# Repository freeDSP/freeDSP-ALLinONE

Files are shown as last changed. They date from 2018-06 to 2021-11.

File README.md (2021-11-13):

# freeDSP ALLinONE
BOARD STATUS: READY TO BE BUILT

Upgrade of the [freeDSP Classic SMD-B](https://github.com/freeDSP/freeDSP-CLASSIC-SMD-B/blob/master/README.md)

LICENCE: Creative Commons Attribution Share-Alike 4.0 license

http://freedsp.cc

## About

The freeDSP is an open-source digital signal processor family for the do-it-yourself community. The applications range from active loudspeaker concepts (digital crossovers, bass enhancement, ...) and room equalization over advanced musical effect processors to car audio signal processing. 

The _freeDSP ALLinONE_ is an all-in-one version of the original _freeDSP Classic SMD-B_ with a few improvements, upgrades and changes.
It features four amplified analog outputs as well as S/PDIF in- and output (optical and RCA).
This board has been designed using the Cross-Platform Open Source Tool [KiCad](http://kicad.org/).

More informations kann be found on the [freeDSP website](http://freedsp.cc)

You can find a PDF version of the schematic in the SOURCES folder (LINK)

## Links

[freeDSP Website](http://freedsp.cc)

[Documentation in Google Doc](https://docs.google.com/document/d/1258PKKEvrk1GpFIaAHhm8G6f0HHNBfSL8KVq2VGgUKc/edit?usp=sharing)

[freeDSP Guidelines](https://github.com/freeDSP/WIKI-AND-GENERAL-TOPICS/wiki/freeDSP-Guidelines)

## Git usage

#### How to setup local repository
- Change to your FreeDSP directory
- Clone the repository (including submodule)  
 `git clone --recursive https://github.com/freeDSP/freeDSP-ALLinONE.git` 
- Change to the newly created ALLinONE directory
- Checkout a branch for the library submodule, if you want to modify it as well
  `git submodule foreach 'git checkout 'master''`
- Open the project file in KiCad

#### How to update the local copy
- To update the project  
  `git pull`
- To update the library  
  `git submodule update --remote --merge`

#### To commit and push local changes
- If you modified something in the LIBRARY folder, change to the LIBRARY folder and run  
  `git add .` (Only required if files were added)  
  `git commit -am "Message"`  (Describe what you changed)  
- Change to the project root directory and run
  `git add .` (Only required if files were added)  
  `git commit -am "Message"`  (Describe what you changed)    
- In the project directory run  
  `git push --recurse-submodule=on-demand`  

#### Define alias to make things shorter
- In the project directory run
  `git config alias.supdate 'submodule update --remote --merge'`  
  `git config alias.spush 'push --recurse-submodules=on-demand'`  
- Afterwards you can use `git supdate` to update the submodule and `git spush` to push any commited changes  

#### Other useful commands
- `git status`  
  Shows general information about the current branch, uncommited changes, not yet added new files and more
- `git diff`  
  Shows uncommited changes
- `git reset --hard origin/master`
  Reset all files to the current status of the dev-hs-01 branch on the Github repository  
  **Careful** This deletes all local changes, so make sure all changes you made and you do not want to delete are pushed to the remote repository

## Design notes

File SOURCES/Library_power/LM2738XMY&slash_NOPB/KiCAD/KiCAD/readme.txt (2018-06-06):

 

**********************************************************
*************  Important Instructions Follow  ************
**********************************************************
 
All files exported to: C:\EMA\ExportFolder\0\224220\Output\KiCAD\KiCAD\symbols.lib

After you have used Ultra Librarian to export library:
**************************************************
**To import your new library symbols into KiCad:**
**************************************************
1. Open KiCad.
2. On the program/tool list, go to Eeschema.
3. Select *Preferences* from the menu bar then select *Library*.
4. Click *Add* and choose the newly exported *.LIB* file.
5. You have now successfully imported your new symbol library!

**************************************************************
**To import your new library footprints/patterns into KiCad:**
**************************************************************
1. Open KiCad.
2. On the program/tool list, go to Pcbnew.
3. Follow the same steps as you would importing symbols, only this time select the *.kicad_mod* file.
4. You have now successfully imported your new footprint/pattern.

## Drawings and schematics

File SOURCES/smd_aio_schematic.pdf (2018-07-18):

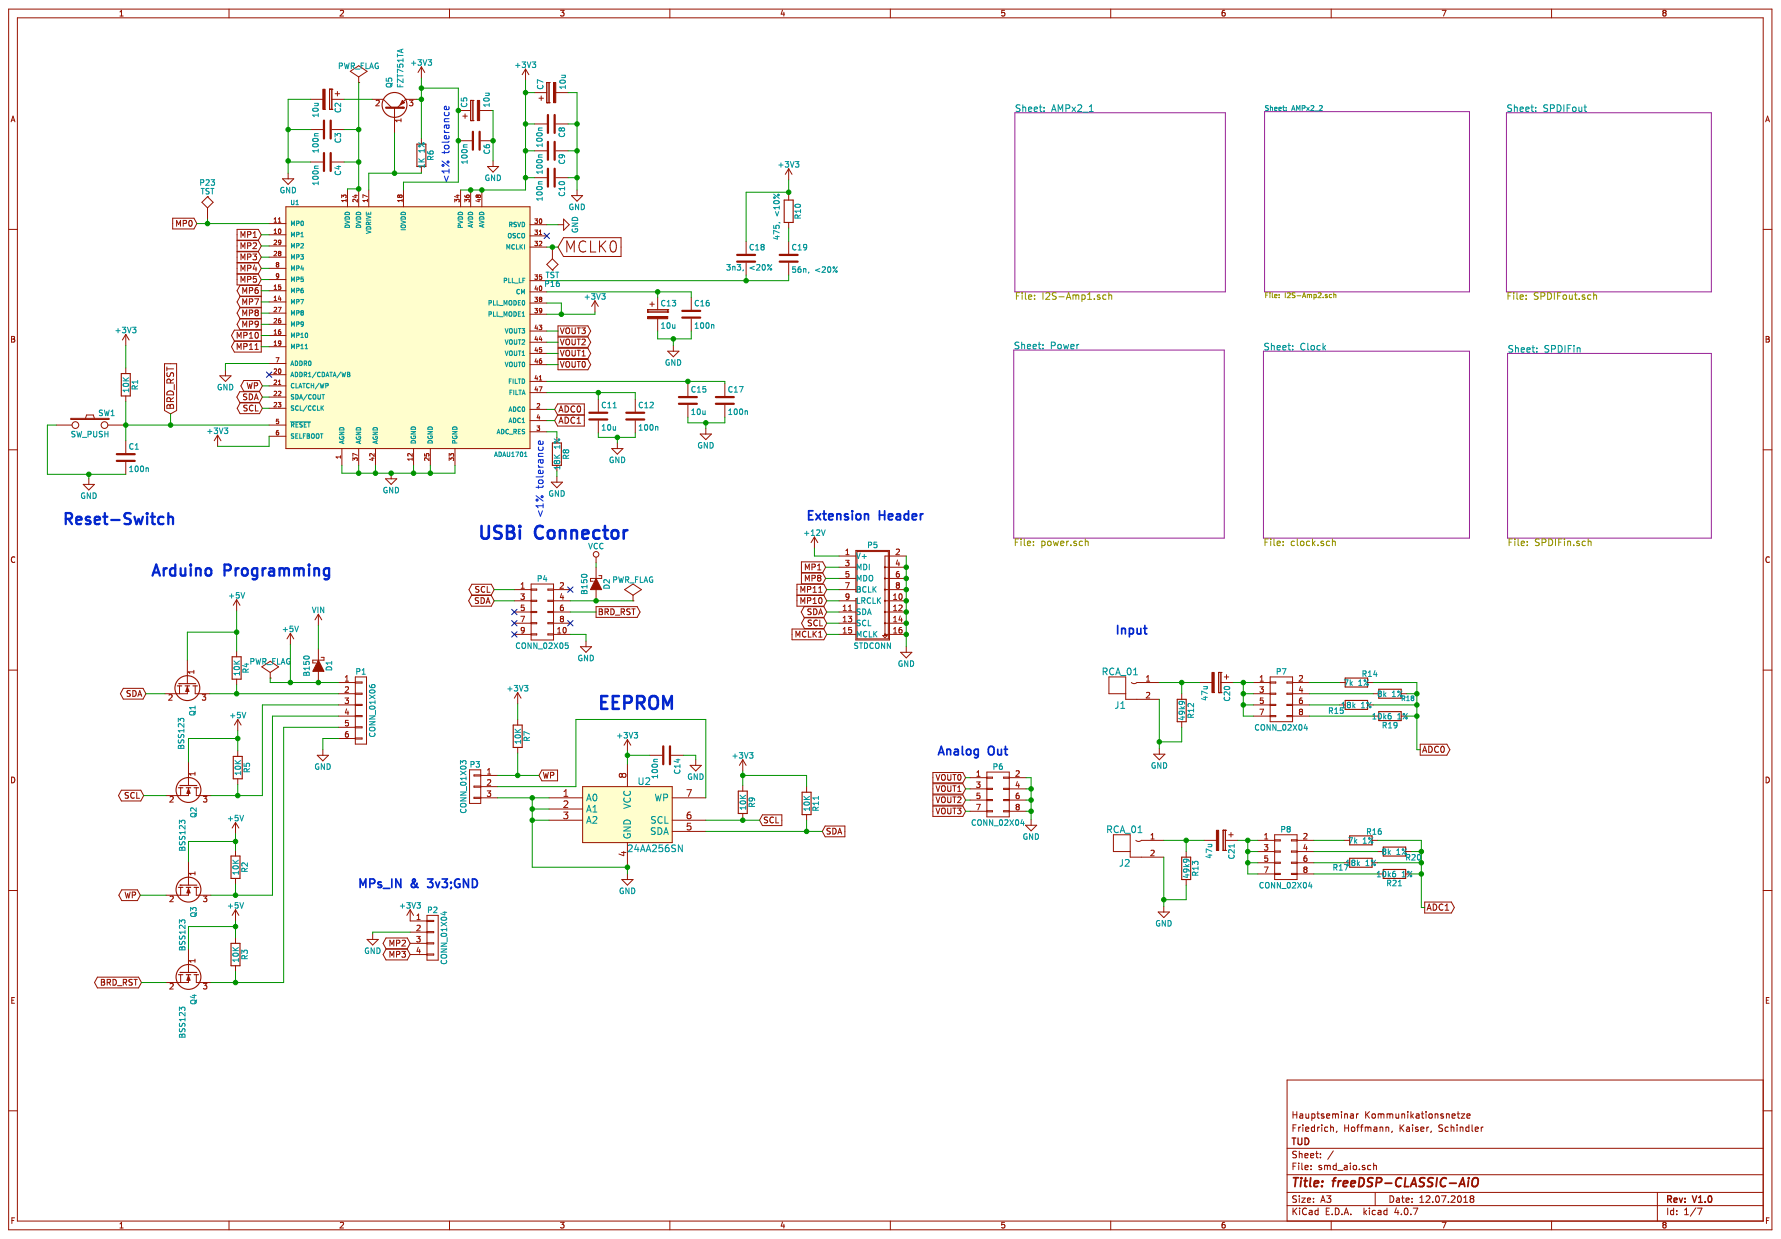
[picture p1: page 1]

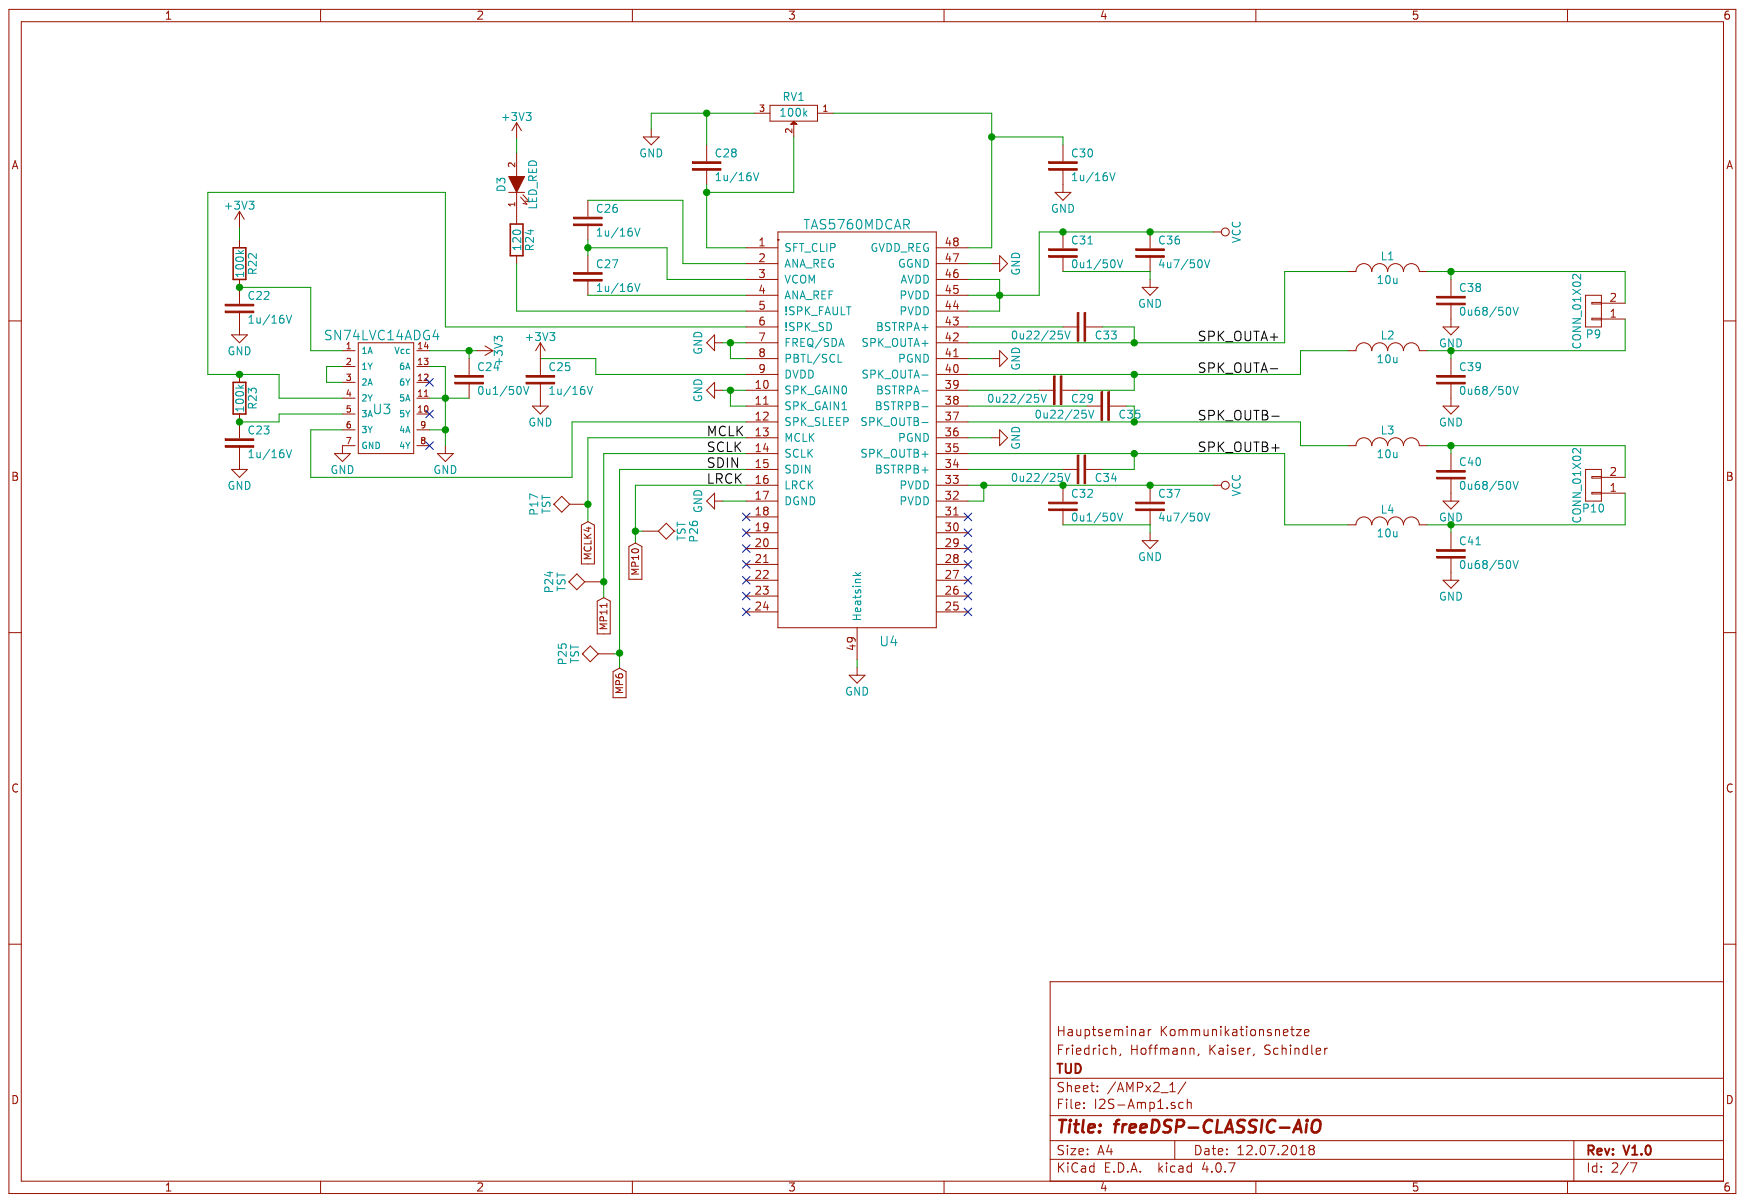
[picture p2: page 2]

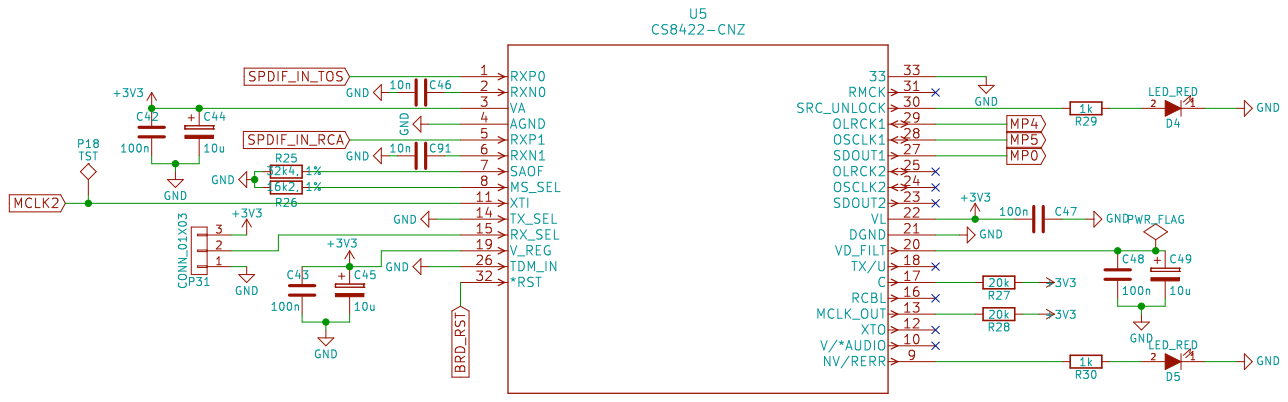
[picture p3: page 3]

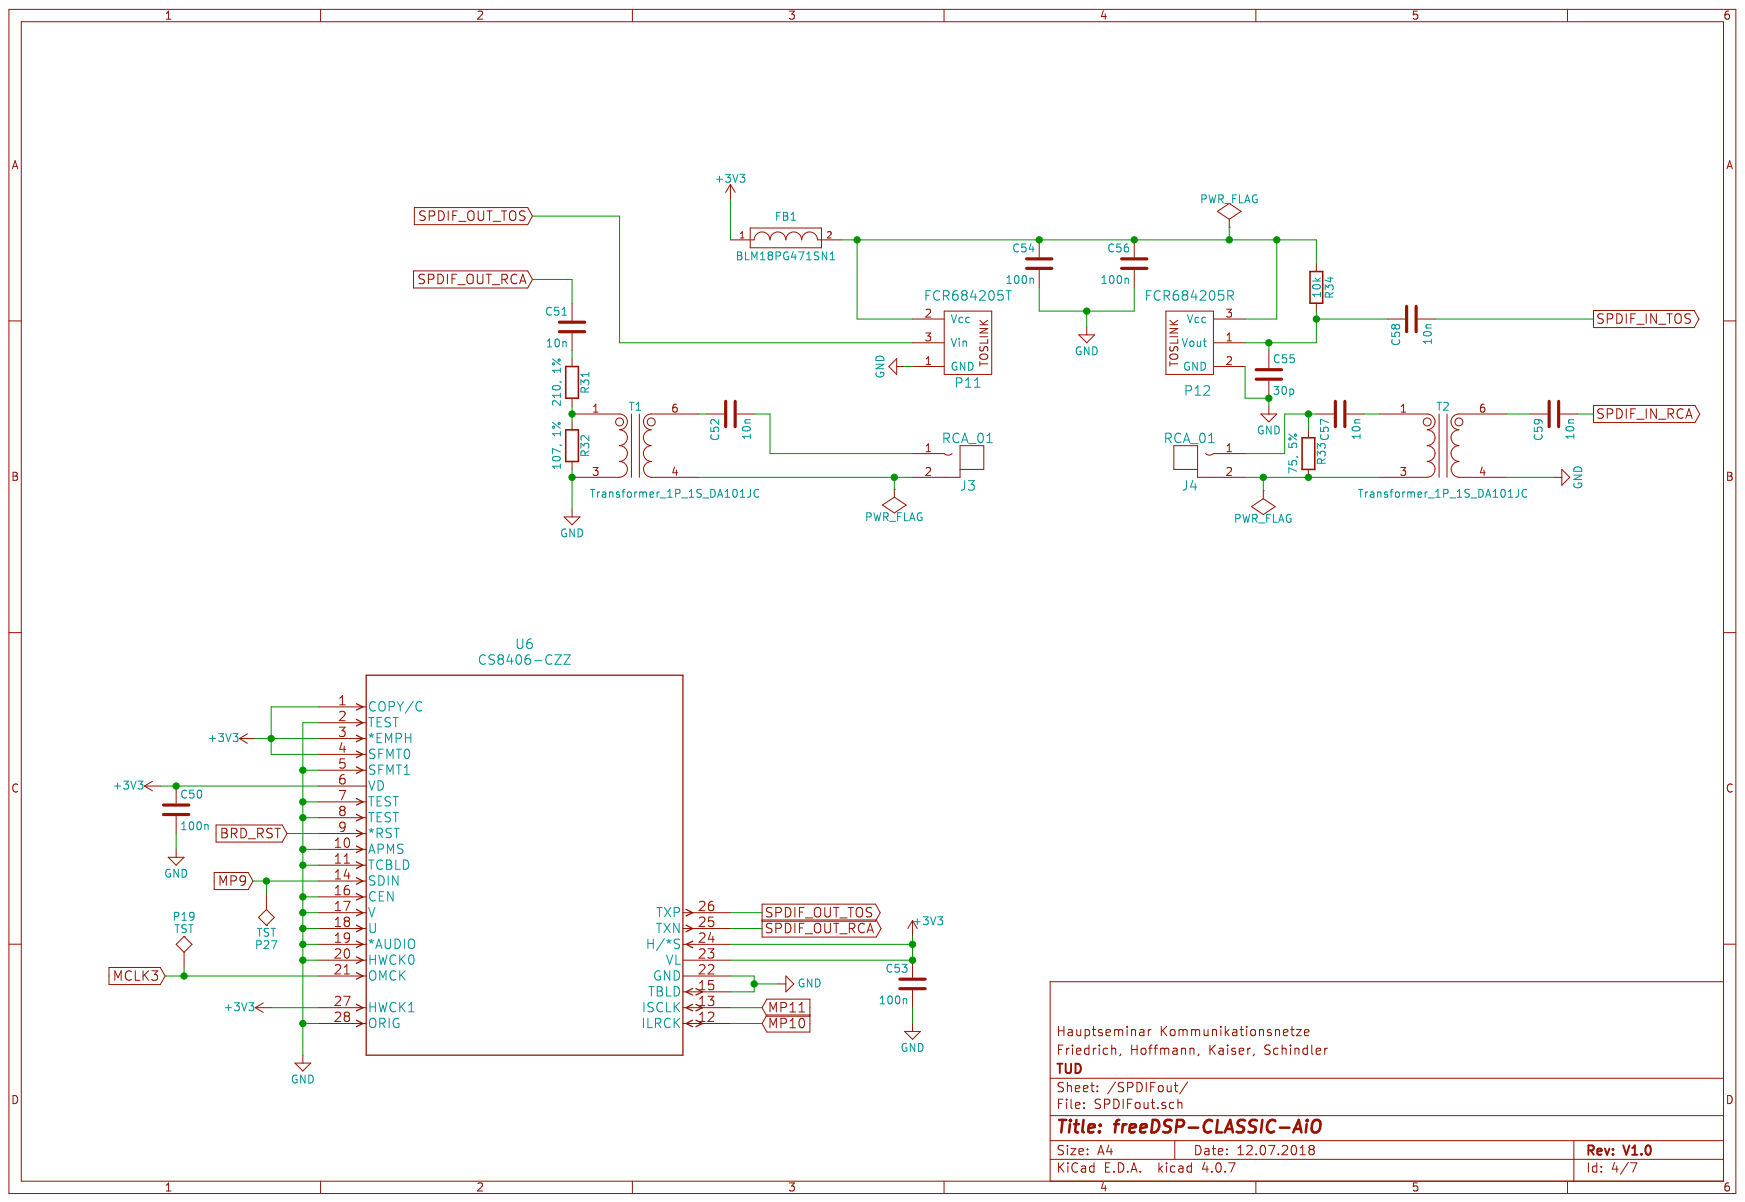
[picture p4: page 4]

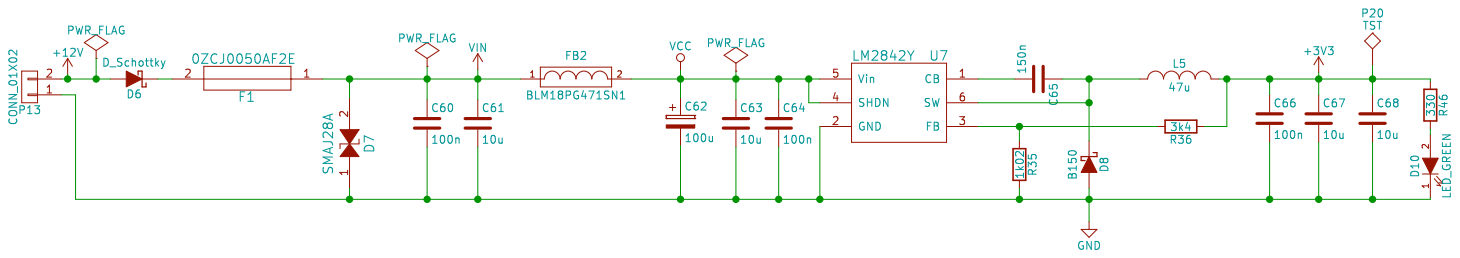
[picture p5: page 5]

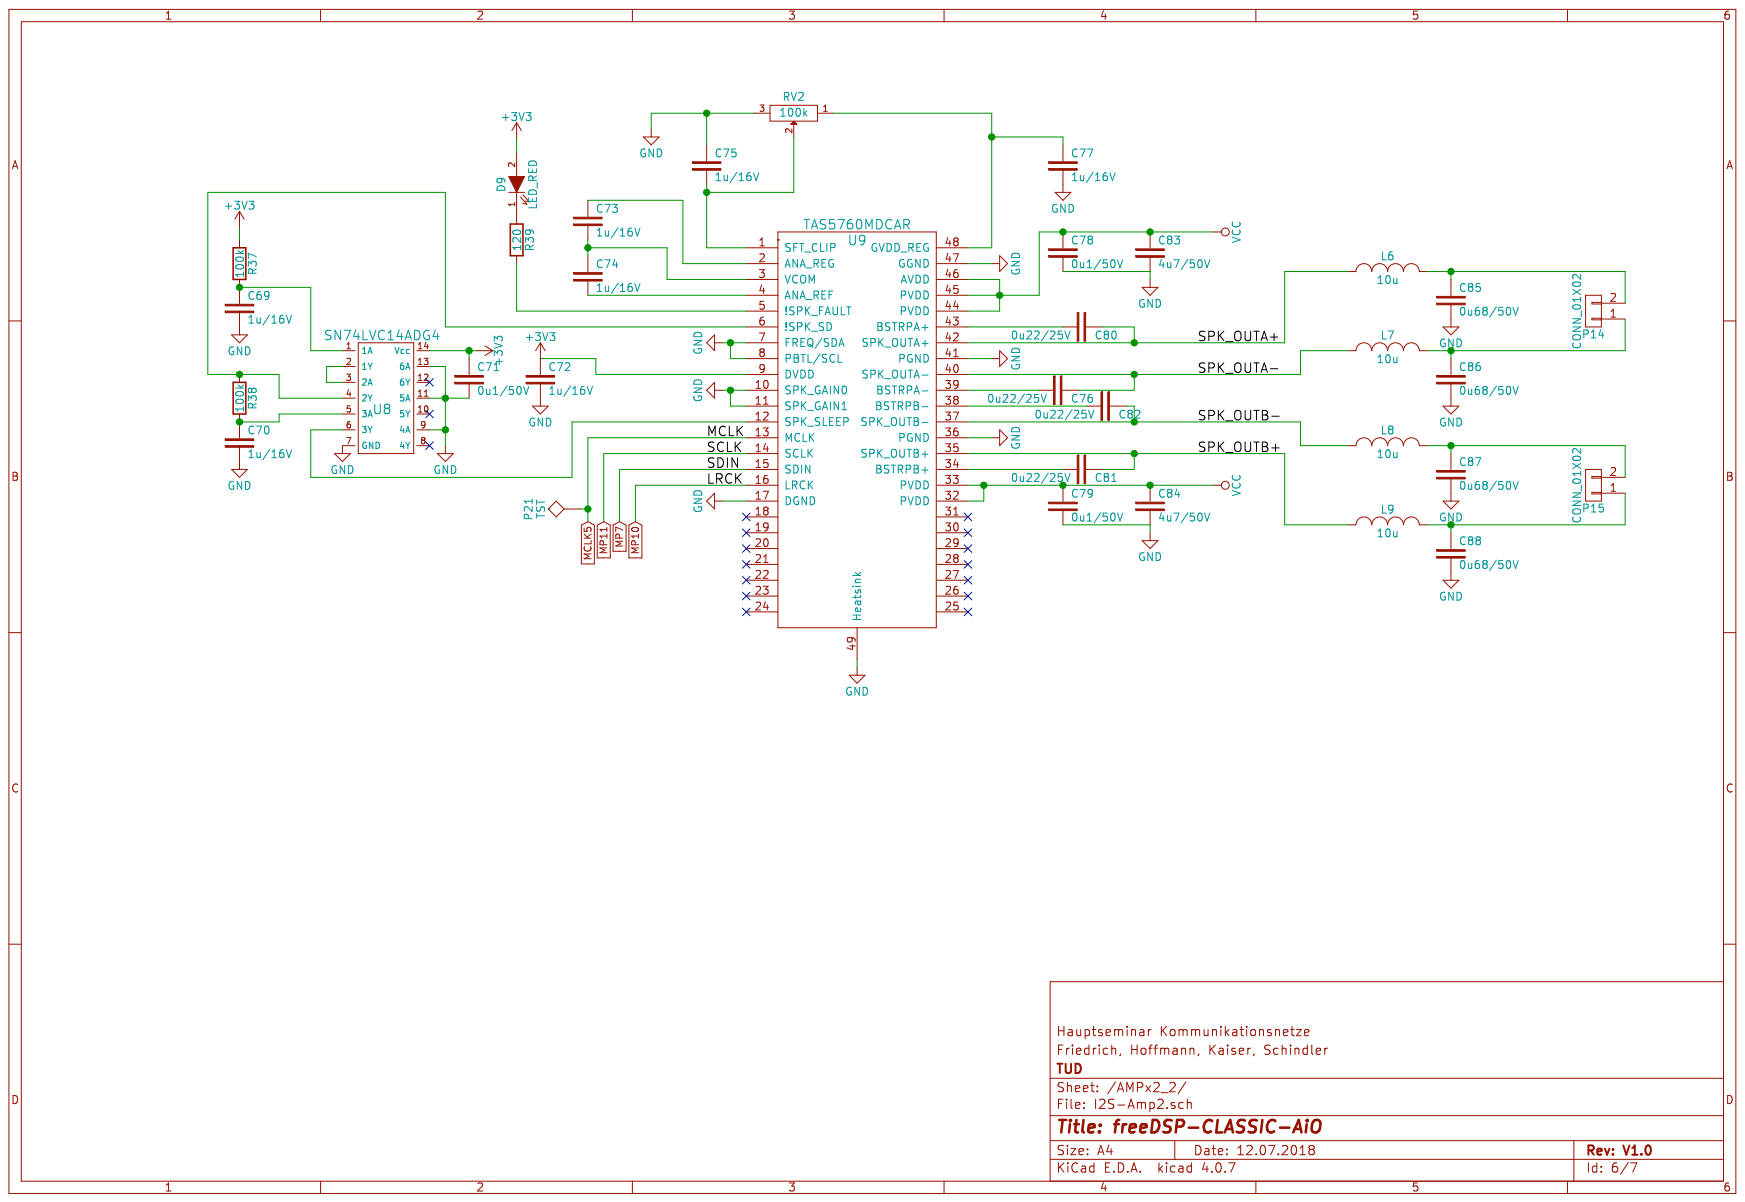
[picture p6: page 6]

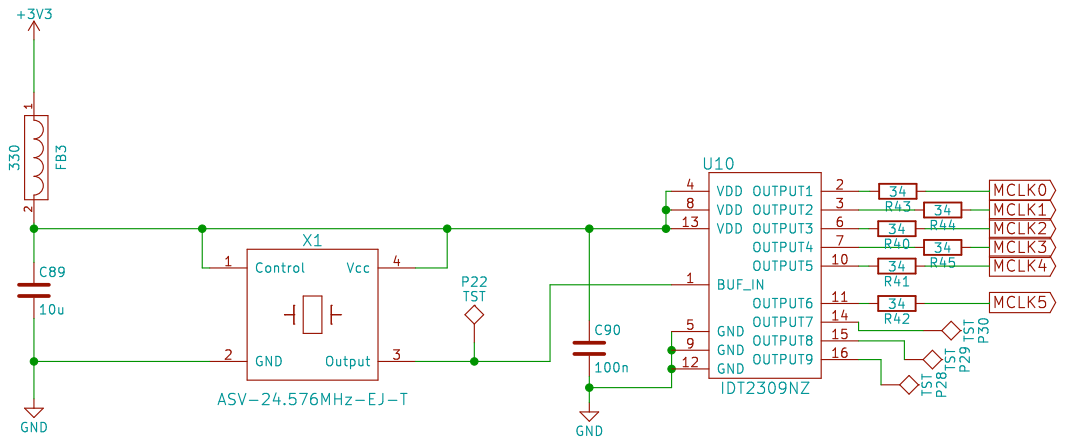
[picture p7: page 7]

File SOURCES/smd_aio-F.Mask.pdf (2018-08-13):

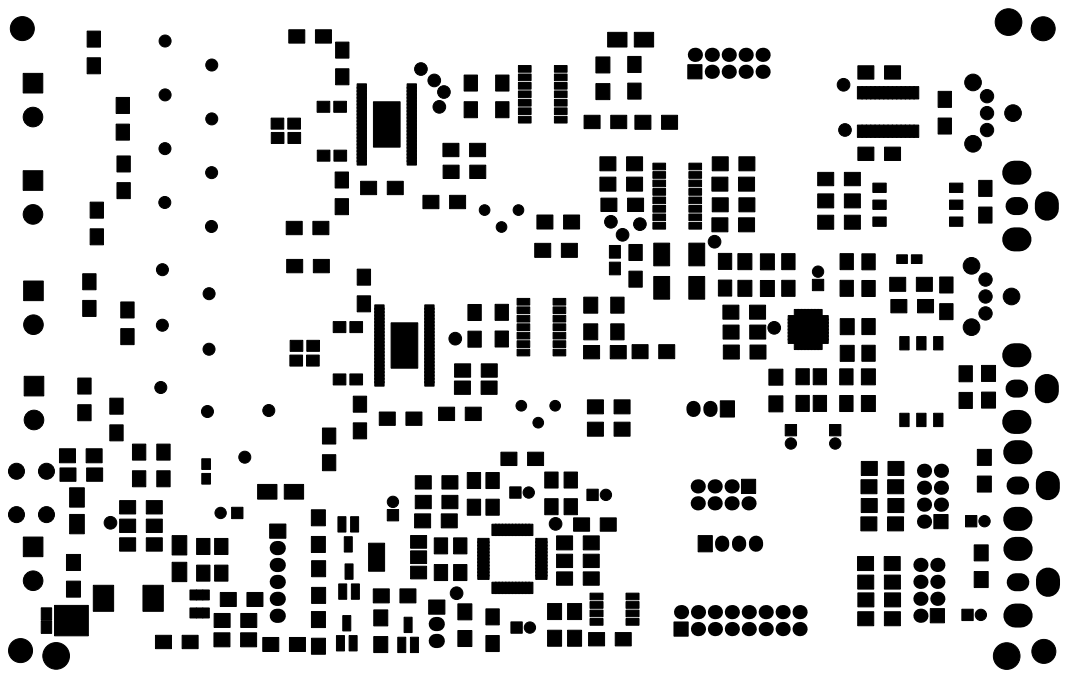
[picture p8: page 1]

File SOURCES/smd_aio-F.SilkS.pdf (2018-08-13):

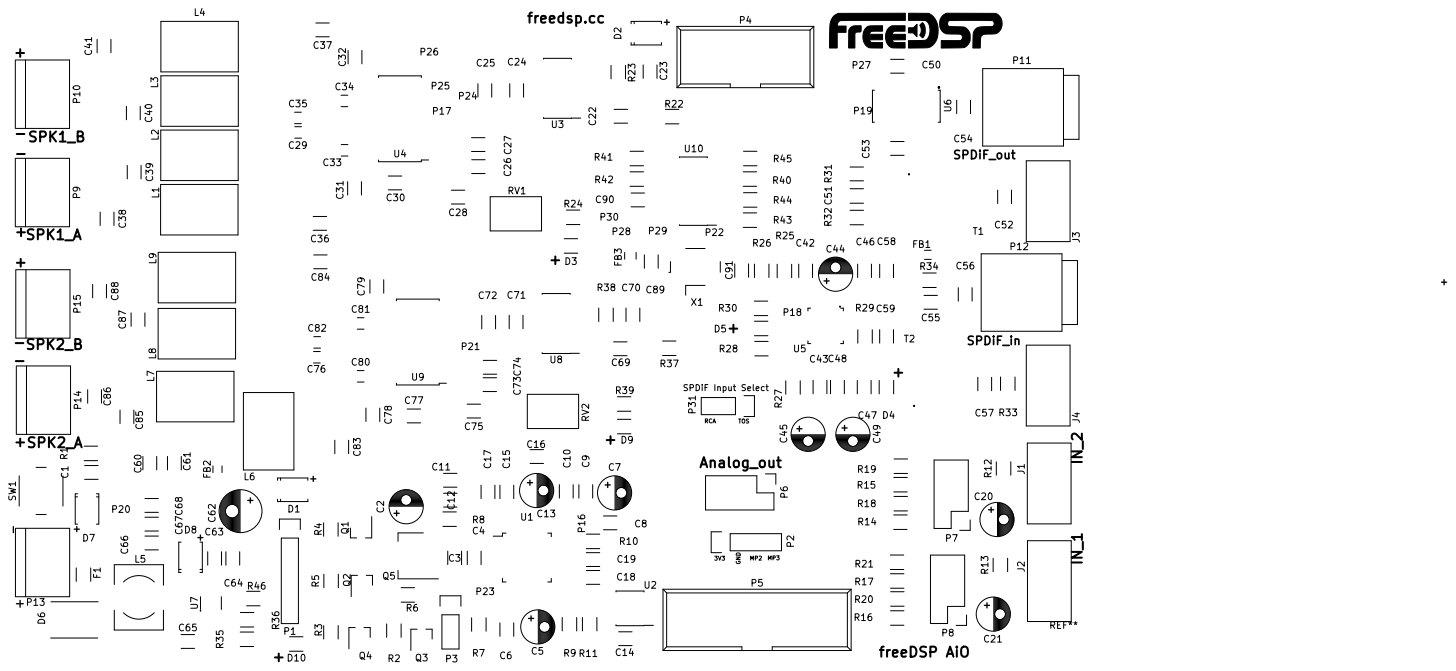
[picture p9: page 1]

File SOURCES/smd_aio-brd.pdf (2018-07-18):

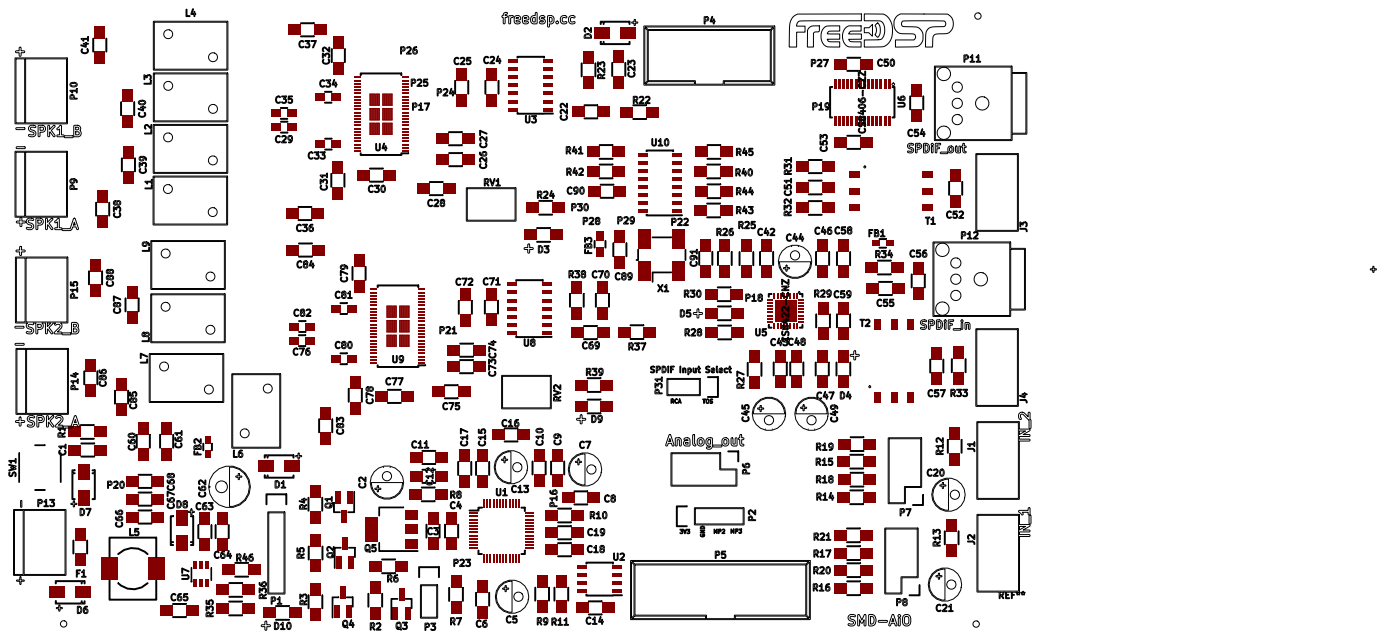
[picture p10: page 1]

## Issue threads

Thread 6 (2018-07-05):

Q5 3D-Modell

michael-schindler, 2018-07-05:
Das 3D-Modell des Q5 ist schlicht falsch. Es gibt zwei Möglichkeiten, das zu fixen:

1. In der custom-Bibliothek fdsp_transistors_new den 3D-footprint anpassen
2. Den Standard footprint von KiCad SOT-223 verwenden

Beide sind mit Arbeit verbunden: Das Warten von custom-Bibliotheken ist generell aufwändig und eine häufige Fehlerquelle. Beim Einfügen des Standard-footprints hingegen müssen Pin 2 und Pin 4 logisch miteinander verknüpft werden (Im Bauteil sind ja beides Kollektor Pins).

Closed 2018-11-18.

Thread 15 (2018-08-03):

Einheitlicher Name

KaiFra, 2018-08-03:
In Absprache mit Tom hatten wir uns auf "freeDSP AiO" als Name für unser Projekt geeinigt.
Deswegen sollten wir hier und im Doc alles bis zur Abgabe vereinheitlicht haben.

michael-schindler, 2018-10-31:
> Wir haben uns jetzt auf freeDSP ALLinONE geeinigt

Na dann würde ich das Issue an dieser Stelle mal schließen, zumal wir ja jetzt ohnehin live sind.

KaiFra, 2018-10-31:
Naja, auf dem PCB steht es noch nicht so und im GS sind die Bilder damit auch veraltet

Closed 2018-11-18.

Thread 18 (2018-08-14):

Wiki auf neusten Stand bringen

KaiFra, 2018-08-14:
Hat jetzt nicht unbedingt Priorität, aber bei freien Kapazitäten könnte man das Wiki noch aufhübschen, komplett auf Englisch halten und es auf denselben Stand wie das Doc bringen
Also Bilder einfügen und die Leiste an der Seite anpassen, sodass es eine Unterleiste gibt, wenn man auf Messungen geht

michael-schindler, 2018-10-31:
> Messungen einpflegen

Das ist ja bereits im #20 dabei. #18 ist für das Allgemeine.

KaiFra, 2018-11-18:
done

Closed 2018-11-18.

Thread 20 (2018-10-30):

Messungen aus dem Getting Started ins Wiki verschieben

KaiFra, 2018-10-30:
Moin, ich habe gerade mit Sebastian geredet und wir haben uns darauf geeinigt, die Messungen aus dem Getting Started ins Wiki zu verschieben, um den Endanwender nicht unnötig zu überfordern.

KaiFra, 2018-11-14:
@michael-schindler Schieb mal bitte alle Fotos ins Git, dann mache ich die Tage mal die Artikel, damit wir mal nen Schlussstrich ziehen können

KaiFra, 2018-11-18:
done

Closed 2018-11-18.

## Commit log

2018-05-11 first git test
    [smd_aio.kicad_pcb, smd_aio.sch]
2018-05-11 DSP angeschlossen
    [smd_aio.sch]
2018-05-12 Struktur angepasst
    [smd_aio.kicad_pcb, smd_aio.sch]
2018-05-12 kicad new lib
2018-05-14 continued on base design
    [smd_aio.sch]
2018-05-14 one amp_x2 added
    [I2S-Amp.sch, smd_aio.sch]
2018-05-15 added sheets
    [I2S-Amp.sch, smd_aio.sch]
2018-05-15 test dev
    [SPDIFin.sch]
2018-05-16 test merge amp
    [power.sch]
2018-05-18 Kopie vom SMD-B und kleine Anpassungen
2018-05-22 adding AMPx2 done
    [I2S-Amp1.sch, I2S-Amp2.sch, SPDIFin.sch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]
2018-05-22 rearranged sheets
    [smd_aio.sch]
2018-05-22 added I2S interface
    [smd_aio.sch]
2018-05-22 added SPDIF lib & analog out
    [I2S-Amp1.sch, I2S-Amp2.sch, SPDIFin.sch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]
2018-05-23 added analog input
    [I2S-Amp1.sch, I2S-Amp2.sch, SPDIFin.sch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]
2018-05-23 added clock + extended lib
    [I2S-Amp1.sch, I2S-Amp2.sch, SPDIFin.sch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]
2018-05-23 added clock
    [clock.sch]
2018-05-26 added lib power
2018-05-31 IDT2309 clock buffer added
    [clock.sch, smd_aio.sch]
2018-06-01 added power
    [I2S-Amp1.sch, I2S-Amp2.sch, power.sch]
2018-06-06 Spdif Schaltpläne
    [SPDIFin.sch, SPDIFout.sch]
2018-06-06 Spdif externe Peripherie
    [SPDIFout.sch]
2018-06-06 modifications amp
    [I2S-Amp1.sch, I2S-Amp2.sch, clock.sch]
2018-06-06 design rule check
    [I2S-Amp1.sch, I2S-Amp2.sch, SPDIFin.sch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]
2018-06-11 finished drc
    [I2S-Amp1.sch, I2S-Amp2.sch, SPDIFin.sch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]
2018-06-12 assign footprints
    [I2S-Amp1.sch, I2S-Amp2.sch, SPDIFin.sch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]
2018-06-12 Toslink Buchsen
    [SPDIFout.sch]
2018-06-13 FCR lib
    [SPDIFout.sch]
2018-06-13 almost done footprints
    [I2S-Amp1.sch, I2S-Amp2.sch, SPDIFout.sch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]
2018-06-13 transformer footprint
2018-06-14 added tolerance
    [SPDIFout.sch, smd_aio.sch]
2018-06-14 kleine Anpassungen
    [SPDIFin.sch, SPDIFout.sch, smd_aio.sch]
2018-06-15 started layout
    [I2S-Amp1.sch, I2S-Amp2.sch, SPDIFin.sch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]
2018-06-16 updated bom
2018-06-17 layout started
    [smd_aio.kicad_pcb]
2018-06-18 added choke footprint
2018-06-19 layout weiter
    [smd_aio.kicad_pcb]
2018-06-20 layout spdif and adau
    [smd_aio.kicad_pcb]
2018-06-22 layout, neue Clock Zuordnung
    [I2S-Amp1.sch, I2S-Amp2.sch, SPDIFin.sch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]
2018-06-25 new layout power
    [smd_aio.kicad_pcb]
2018-06-26 SPDIF only TOSLINK
    [I2S-Amp2.sch, SPDIFout.sch, clock.sch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]
2018-06-29 fixed SPDiF (RCA)
    [I2S-Amp1.sch, I2S-Amp2.sch, SPDIFin.sch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]
2018-06-29 layout incl. spdif
    [I2S-Amp1.sch, I2S-Amp2.sch, SPDIFin.sch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]
2018-07-02 gerber files added
    [smd_aio-B.Cu.gbl, smd_aio-B.Mask.gbs, smd_aio-B.Paste.gbp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]
2018-07-02 gerber fix
    [smd_aio.kicad_pcb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]
2018-07-05 updated Gerber Files
    [smd_aio-B.Cu.gbl, smd_aio-B.Mask.gbs, smd_aio-B.Paste.gbp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]
2018-07-05 updated references
    [SPDIFin.sch, SPDIFout.sch, power.sch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]
2018-07-18 assembly print
    [I2S-Amp1.sch, I2S-Amp2.sch, SPDIFin.sch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]
2018-07-27 issue #9
    [smd_aio.kicad_pcb, smd_aio.sch]
2018-07-31 added footprint
2018-07-31 D6D7 updatet
    [power.sch, smd_aio.kicad_pcb]
2018-08-01 P4 boxed
    [smd_aio.sch]
2018-08-04 new name
    [smd_aio.kicad_pcb]
2018-08-11 updated readme
    Namens- und Linkanpassungen
2018-08-13 fuse and vin to header
    [power.sch, smd_aio.kicad_pcb, smd_aio.sch]
2018-08-13 program folder
    [smd_aio.kicad_pcb]
2021-11-09 Update README.md
    https://forum.kicad.info/t/warning-avoid-all-links-to-kicad-pcb-org-use-kicad-org/31521
